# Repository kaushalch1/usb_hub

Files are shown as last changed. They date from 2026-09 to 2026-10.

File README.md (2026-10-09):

# Travel USB Hub

A compact USB 2.0 hub designed for portability and everyday use. This project expands a single USB connection into multiple ports by providing **two USB-A ports and one USB-C port**, making it a convenient accessory for students, developers, and travelers.

## Why did i build it?

Modern laptops and tablets often have a limited number of USB ports, requiring users to carry multiple adapters or repeatedly plug and unplug devices. The Travel USB Hub solves this problem by combining multiple USB interfaces into a single compact PCB.

Built around the **CoreChips SL2.1A USB 2.0 Hub Controller**, the hub supports both data transfer and power delivery for compatible USB devices.

## Features

- 1 USB-A upstream port for connecting to a host computer
- 2 USB-A downstream ports
- 1 USB-C downstream port
- USB 2.0 data transfer support
- current protection using a Schottky diode
- 10 µF capacitor for power stabilizatio
- Compact and travel-friendly PCB design

## Components Used

| CoreChips SL2.1A 
| USB-A Male Connector
| USB-A Female Connectors (2x)
| USB-C Receptacle
| Schottky Diode
| 10 µF Capacitor 
| 5.1 kΩ Resistors (2x) 

## Why This Project Is Useful for Travel

Many modern laptops provide only one or two USB ports, making it difficult to connect multiple accessories simultaneously. This travel hub combines legacy USB-A compatibility with modern USB-C connectivity in a single compact device.

It is useful for:

- Connecting flash drives
- Using keyboards and mice
- Programming microcontroller boards
- Connecting USB-C accessories
- Charging compatible USB devices
- Working while travelling without carrying multiple adapters

Its compact PCB design allows it to fit easily inside a backpack, laptop sleeve, or travel pouch.

## Design Tools

- KiCad
- EasyEDA/LCSC component libraries
-fusion 360

pcb


schematics


3d model


3d model top panel


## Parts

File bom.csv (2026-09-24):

Reference | Qty | Value | DNP | Exclude from BOM | Exclude from Board | Footprint | Datasheet
C1,C2,C3 | 3 | 10uF |  |  |  | Capacitor_SMD:CP_Elec_4x5.4
D1 | 1 | D_Schottky |  |  |  | Diode_SMD:D_2114_3652Metric
J1 | 1 | USB_C_Receptacle_USB2.0_16P |  |  |  | Connector_USB:USB_C_Receptacle_HCTL_HC-TYPE-C-16P-01A | https://www.usb.org/sites/default/files/documents/usb_type-c.zip
R1,R2 | 2 | 5.1k |  |  |  | Resistor_SMD:R_0805_2012Metric
U1 | 1 | SL2.1A |  |  |  | EasyEDA:SOP-16_L10.0-W3.9-P1.27-LS6.0-BL | https://lcsc.com/product-detail/Others_CoreChips-SL2-1A_C192893.html
USB1 | 1 | U-G-04DD-W-01 |  |  |  | EasyEDA:USB-A-TH_U-G-04WD-W-01 | https://lcsc.com/product-detail/USB-Connectors_USBConnector-900-Board-Iron-feet-tray_C98125.html
USB2,USB3 | 2 | USB-AF-90-14.4X13.6-H7.0-DIP |  |  |  | EasyEDA:USB-A-TH_C46407 | https://lcsc.com/product-detail/USB-Connectors_A-F90-White-plastic-Not-high-temperature_C46407.html

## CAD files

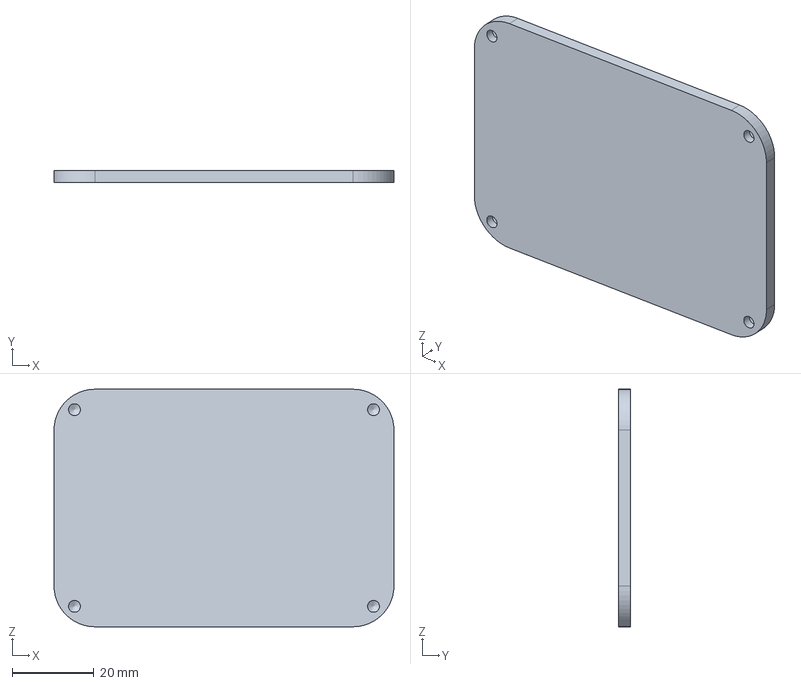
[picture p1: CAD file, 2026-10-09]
cad files/top panel.step
83.0 x 3.00 x 58.0 mm

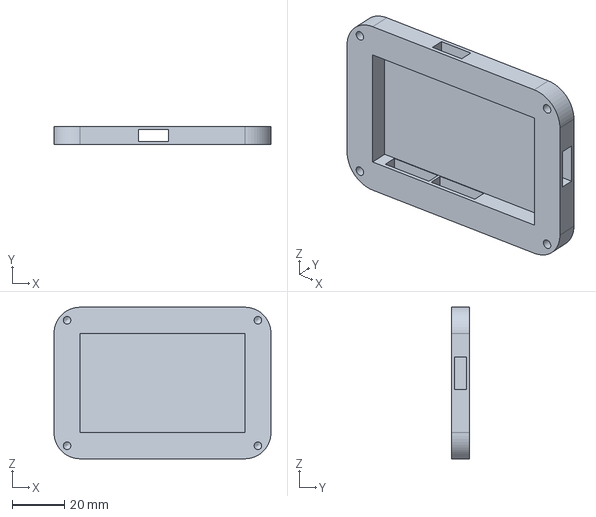
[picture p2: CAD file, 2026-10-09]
cad files/bottom panel.step
83.0 x 7.00 x 58.0 mm

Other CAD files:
cad files/bottom panel.f3d
cad files/top panel.f3d

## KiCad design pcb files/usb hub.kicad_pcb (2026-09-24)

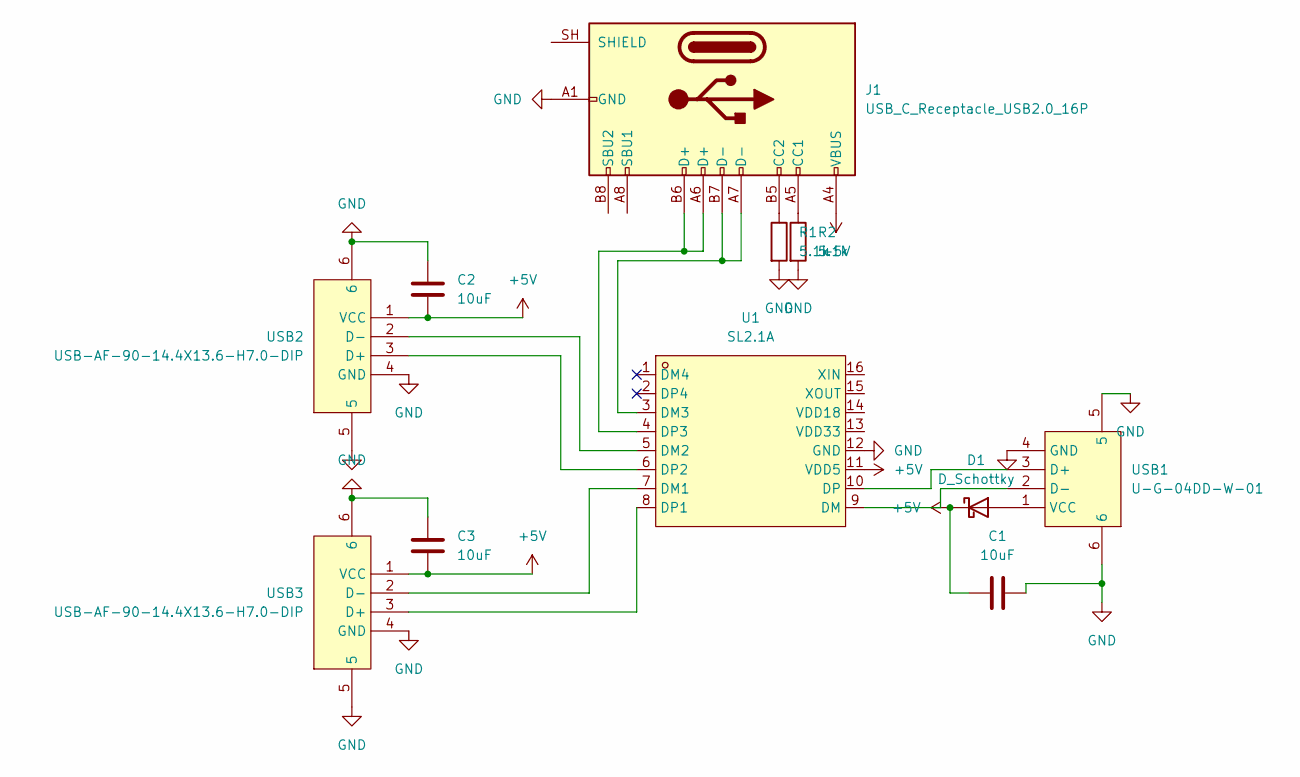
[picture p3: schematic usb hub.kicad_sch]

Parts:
C1, C2, C3: 10uF; CP_Elec_4x5.4
D1: D_Schottky; D_2114_3652Metric
J1: USB_C_Receptacle_USB2.0_16P; USB_C_Receptacle_HCTL_HC-TYPE-C-16P-01A
R1, R2: 5.1k; R_0805_2012Metric
U1: SL2.1A; SOP-16_L10.0-W3.9-P1.27-LS6.0-BL; MPN SL2.1A; LCSC Part C192893
USB1: U-G-04DD-W-01; USB-A-TH_U-G-04WD-W-01; MPN U-G-O4DD-W-1; LCSC Part C98125
USB2, USB3: USB-AF-90-14.4X13.6-H7.0-DIP; USB-A-TH_C46407; MPN 903-131A1011D10100; LCSC Part C46407

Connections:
+5V: C1.1, C2.1, C3.1, D1.1 (K), J1.A4 (VBUS), J1.A9 (VBUS), J1.B4 (VBUS), J1.B9 (VBUS), U1.11 (VDD5), USB2.1 (VCC), USB3.1 (VCC)
GND: C1.2, C2.2, C3.2, J1.A1 (GND), J1.A12 (GND), J1.B1 (GND), J1.B12 (GND), R1.2, R2.2, U1.12 (GND), USB1.4 (GND), USB1.5, USB1.6, USB2.4 (GND), USB2.5, USB2.6, USB3.4 (GND), USB3.5, USB3.6
unnamed: D1.2 (A), USB1.1 (VCC)
unnamed: J1.A5 (CC1), R2.1
unnamed: J1.B5 (CC2), R1.1
unnamed: U1.7 (DM1), USB3.2 (D-)
unnamed: U1.5 (DM2), USB2.2 (D-)
unnamed: J1.A7 (D-), J1.B7 (D-), U1.3 (DM3)
unnamed: U1.9 (DM), USB1.2 (D-)
unnamed: U1.8 (DP1), USB3.3 (D+)
unnamed: U1.6 (DP2), USB2.3 (D+)
unnamed: J1.A6 (D+), J1.B6 (D+), U1.4 (DP3)
unnamed: U1.10 (DP), USB1.3 (D+)

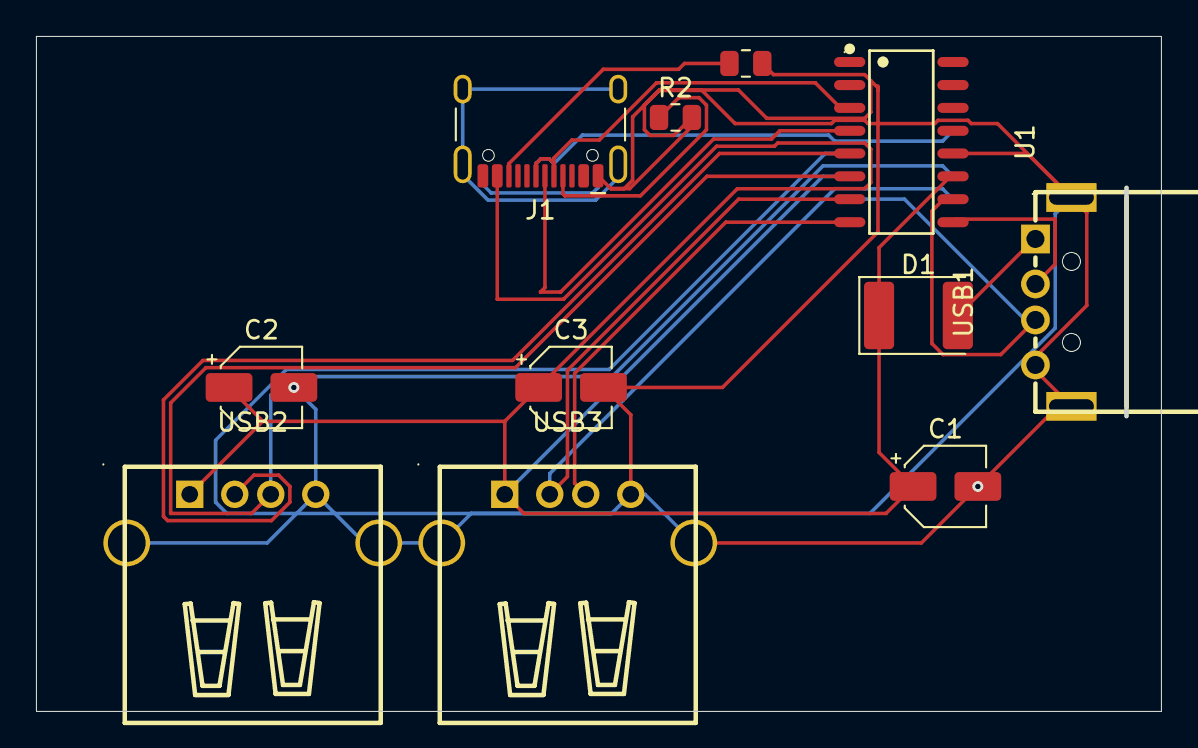
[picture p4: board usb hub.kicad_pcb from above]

Board: 2 copper layers, 62.5 x 37.5 mm, 11 parts (0 on the bottom side), 13 nets.

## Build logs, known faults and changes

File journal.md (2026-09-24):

# date:22/9
# time spent:0.75hr
## description:
I have got all the parts which were4 but I  was confused what to connect then I remembered the cconnections of macropad from there I added them in the schematic editor and then connected the  sl2 to usb a male and then from sl2 to usba female and then I checked the rule checker and got few errors and then fixed them all!! 
## images:



-------
# date:22/9
# time spent:0.5hr
## description:
I learned about the power surges with the before schematics I learned that it is not safer schematics as it may fry the hubb or the computer usb port so I read the CoreChips SL2.1A spec sheet so then I got an idea that we'll add a diode to protect from a surge coming from the laptop and then add a schotkeyy and then connect with diodes and then same is done for the frmale usb a ports but only capacitor is added and then I flagged all the unused ports
## images:


-------
# date:22/9
# time spent:0.75hr
## description:
I started the pcb building and completed the part there were many errors while drawing errors in it because like the all ways were closing for some wires so first I connected the near ones then I connected the far ones,also there were many wires in this usb hub then compare to the macropad project .Now I am going to addd more ports in the schematic so that it will be useful in the travelling
## images:


-------
# date:22/9
# time spent:0.5hr
## description:
I have added a usb c female port that will be useful for travelling also and the honestly the usb-c port has many pins than all the usb a female ports  and I connected all of the usb c ports to the sla2.0 and then I was casually seeing the capacitors of the usb a and I notice that the capacitors don’t have any value, so I manually assign the value 10uf for ll of them and I completed the schematic part of these ya!!
## images:


-------
# date:22/9
# time spent:0.75hr
## description:
I have completed the footprints assigning I assigned the footprints for the resistor,capacitor,and the usb c and then I started the pcb editor it was so many wires ,first I completed the wires connecting the sla to the usb female and now I stuck with the usb c female all ways are stuck I think I should reroute them again at afte sometime I am really confused now where should I start
## images:




-------
# date:22/9
# time spent:0.5hr
## description:
I have just completed all the errors in the rule checker and also in the previous journal I have left some part of the wiring in the before journal now I have done the rerouting of the wire and also I completed the edge cuts of the usb hub,now I should ship :) 
## images:


-------
# date:22/9
# time spent:0.5hr
## description:
I customized the pcb by adding some cool designs in it and also added my favorite pokemons on to the board which were pikachu and zerora and they were to nice in their colors and I figured out that wee can add images to pcb from the image converter
## images:



-------
# date:23/9
# time spent:0.75hr
## description:
First I completed the edge cuts in pcb editor and then I also completed the footprints part and tehn noted the dimensions between ports in notepad and then started the cad modelling part I have just completed the base and also the extruding part and now I should make the top panel and also I should extrude the body inside for the usb ports part
## images:




-------
# date:23/9
# time spent:1hr
## description:
I have completed the holes part of the bottom panel fist so that screws can fit inside it and then I completed the top layer by drawing it and then curving the corners and then punching holes for the screws
## images:



-------
# date:23/9
# time spent:0.5hr
## description:
Now I started drawing the earth in paint and also the countries were from the internet edited the world map and pasted in my drawing and then completed the extruding the blocks and adding the text and then finally appending it into the design and then completed the project by pushing it to the github
## images:



-------

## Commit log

2026-09-24 Added journals
    [bottom panel.f3d, top panel.f3d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]
2026-10-09 added bom files
    [bom.csv]
2026-10-09 added cad files
    [bottom panel.f3d, top panel.f3d]
2026-10-09 added step files
    [bottom panel.step, top panel.step]
2026-10-14 added pcb files
